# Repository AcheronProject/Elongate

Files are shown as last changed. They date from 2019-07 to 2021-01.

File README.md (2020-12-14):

# Acheron 50-SM-S-F072-MX-TH-WI (Codename "Elongate")

Acheron Logo

See [this page](https://gondolindrim.github.io/AcheronDocs/elongate/intro.html) for the ElongatePCB documentation.

## Supported layouts

Click [this link](http://www.keyboard-layout-editor.com/#/gists/a7ea70bf0b0dbade28f4dd3f8dd61796) for the KLE file for Elongate.

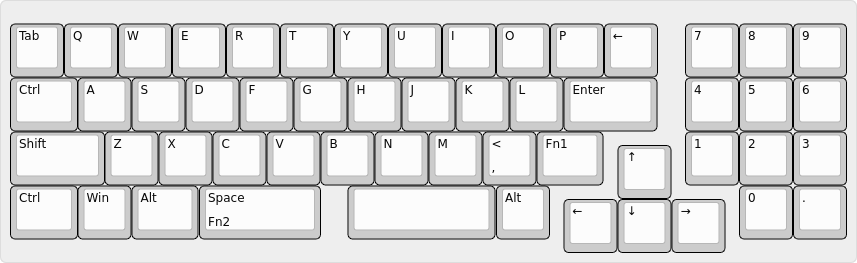
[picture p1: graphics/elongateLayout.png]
Elongate layouts


## Renders

Click at the images to zoom in.

Renders generated by the [tracespace.io](https://tracespace.io/view/) site.

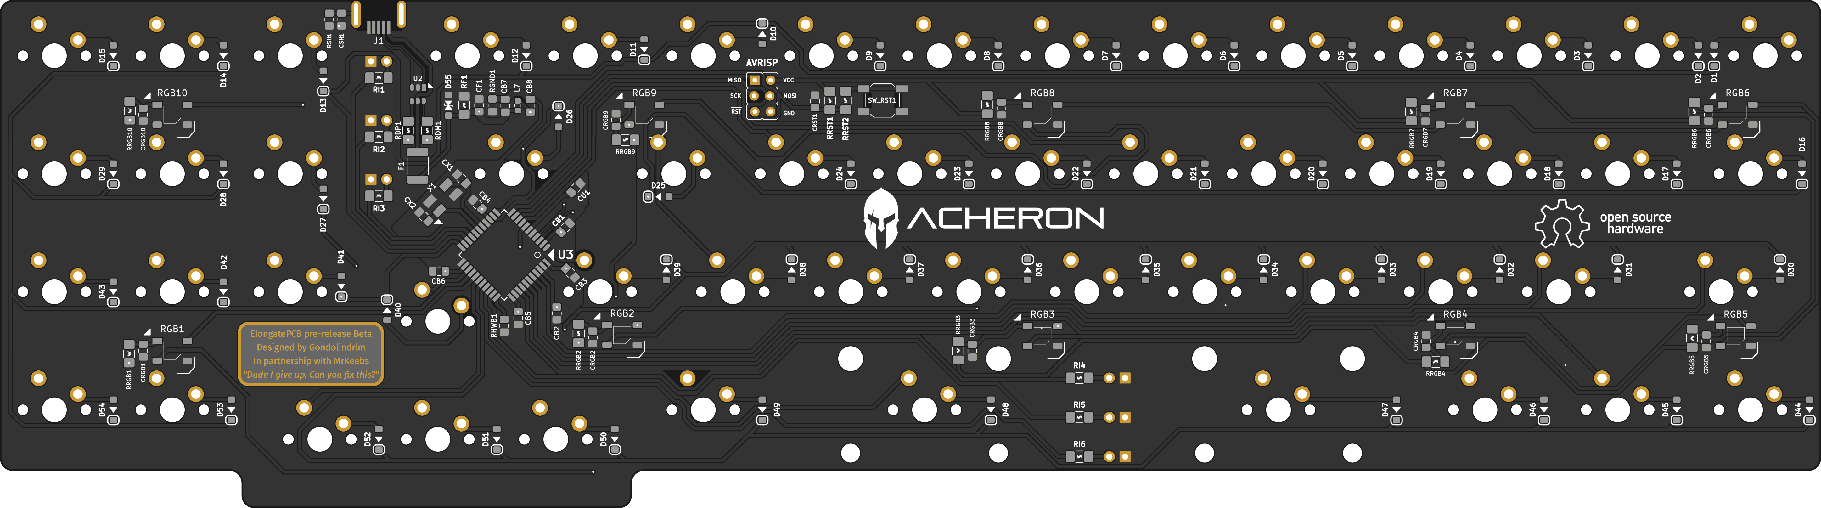
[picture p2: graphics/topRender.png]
Elongate PCB Top Render


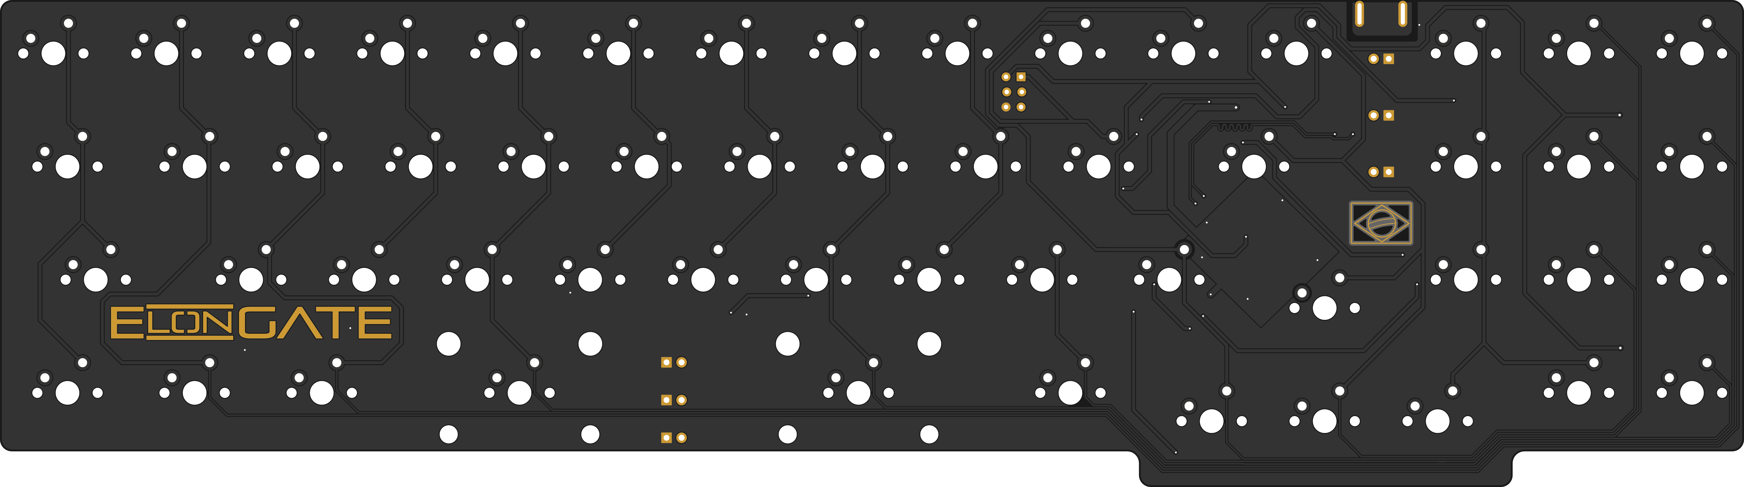
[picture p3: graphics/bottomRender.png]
Elongate PCB Bottom Render


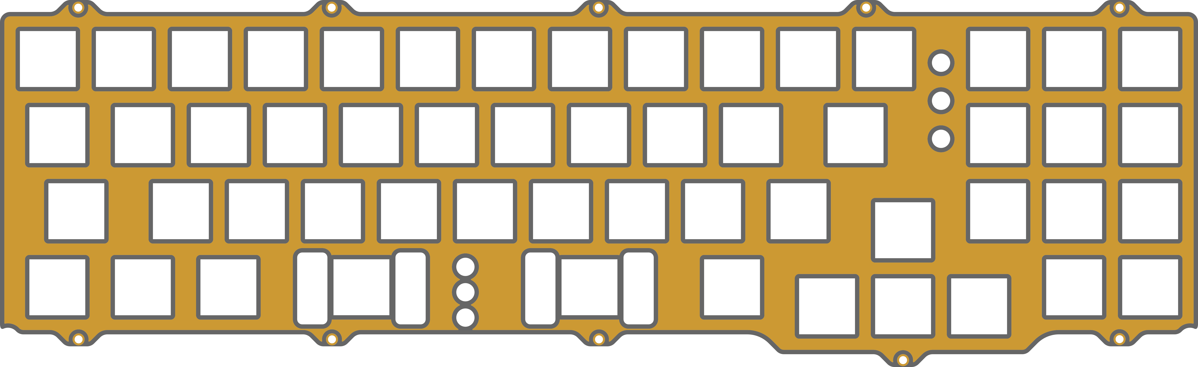
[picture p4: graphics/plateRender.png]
Elongate PCB Plate Render


## Copyright notice

This project is released under the Acheron Open-Hardware License V1.3. For the license, please refer to the LICENCE.md file.

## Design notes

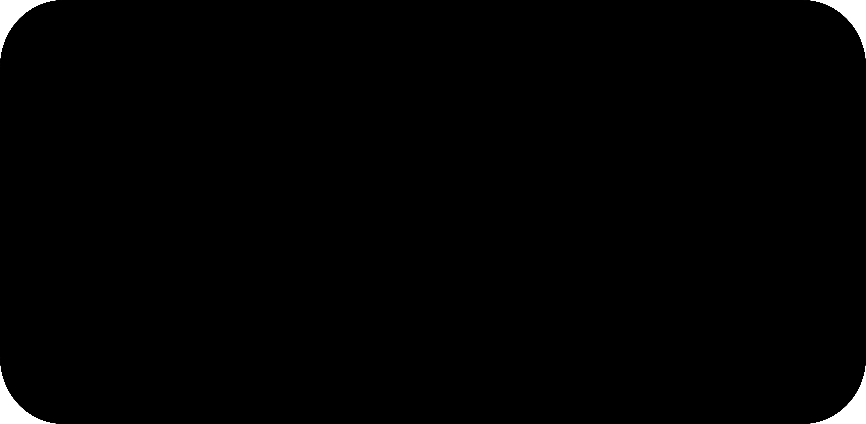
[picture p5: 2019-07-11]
graphics/label_logo/elongateLabelMask.png

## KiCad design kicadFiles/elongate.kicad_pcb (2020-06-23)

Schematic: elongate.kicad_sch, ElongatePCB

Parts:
C1, C2: 100n; C_0805_2012Metric_Pad1.15x1.40mm_HandSolder
C3, C12, C13, C14, C15, C16, C17, C18, C19, C20, C21, C22, C23, C24, C25, C26, C27, C30: 1u; C_0805_2012Metric_Pad1.15x1.40mm_HandSolder
C4, C5, C6, C10: 100n; C_0402_1005Metric
C7, C11: 4.7u; C_0402_1005Metric
C8: 1u; C_0402_1005Metric
C9: 10n; C_0402_1005Metric
C28: 100u; C_0805_2012Metric_Pad1.15x1.40mm_HandSolder
C29: 10u; C_0805_2012Metric_Pad1.15x1.40mm_HandSolder
D1, D2, D3, D4, D5, D6, D7, D8, D9, D10, D11, D12, D13, D14, D15, D16, D17, D18, D19, D20, D21, D22, D23, D24, D25, D26, D27, D28, D29, D30, D31, D32, D33, D34, D35, D36, D37, D38, D39, D40, D41, D42, D43, D44, D45, D46, D47, D48, D49, D50, D51, D52, D53, D54, D72: 1N4148; D_SOD-123
D55: SMF9.0CA; D_SOD-123_Bidirectional; Manufacturer Part Number SMF9.0CA; LCSC Part Number C435473
D56, D57, D58, D59, D60, D61, D62, D63, D64, D65, D66, D67, D68, D69, D70, D71: WS2812C; LED_WS2812B_5.0x5.0mm_P3.2mm; Manufacturer Part Number WS2812C; LCSC Part Number C114587
D73: RB060M-60TR; D_SOD-123; Manufacturer Part Number RB060M-60TR; LCSC Part Number C114257
F1: RF1338-000; Fuse_1812_4532Metric_Pad1.30x3.40mm_HandSolder; Manufacturer Part Number RF1338-000; LCSC Part Number C207188
J1: TYPE-C-31-M12_13; TYPE-C-31-M-12; Manufacturer Part Number TYPE-C-31-M-12; LCSC Part Number C165948
J2: Conn_ARM_JTAG_SWD_10
J3: Conn_01x6; PinHeader_2x3_P2.54mm_Vertical
L1: AcheronLogo; acheronLong
L2: ElongateLogoPlated; elongateLogo
L3: ElongateLabel; elongateLabel
L4: OSHLogo; osh-logo
L5: BRFlag; brazilFlag
LED1, LED2, LED3, LED4, LED5, LED6, LED7, LED8, LED9, LED10, LED11, LED12, LED13, LED14, LED15, LED16, LED17, LED18, LED19, LED20, LED21, LED22, LED23, LED24, LED25, LED26, LED27, LED28, LED29, LED30, LED31, LED32, LED33, LED34, LED35, LED36, LED37, LED38, LED39, LED40, LED41, LED42, LED43, LED44, LED45, LED46, LED47, LED48, LED49, LED50, LED51, LED52, LED53, LED54, LED55, LED56, LED57, LED58, LED59, LED60: LED; LED_THT_2.54mm
Q1, Q3: AO3401A; SOT-23; Manufacturer Part Number AO3401A; LCSC Part Number C15127
Q2, Q4: DTC123JKAT146; SOT-23; Manufacturer Part Number DTC123JKAT146; LCSC Part Number C111724
R1, R2: 5.1k; R_0402_1005Metric
R3, R4: 1M; R_SMD_1206
R5, R6, R7, R8, R9, R10, R14, R15, R16, R17, R18, R19, R20, R21, R22, R23, R24, R25, R26, R27, R28, R29, R30, R31, R32, R33, R34, R35, R36, R37, R38, R39, R40, R41, R42, R43, R44, R45, R46, R47, R48, R49, R50, R51, R52, R53, R54, R55, R56, R57, R58, R59, R60, R61, R62, R63, R64, R65, R66, R67: 390R; R_SMD_1206
R11, R88, R90: 100k; R_SMD_1206
R12, R84, R86: 10k; R_SMD_1206
R13, R89: 100R; R_SMD_1206
R68, R69, R70, R71, R72, R73, R74, R75, R76, R77, R78, R79, R80, R81, R82, R83: 3R; R_SMD_1206
R85: 5.1k; R_SMD_1206
R87: 33k; R_SMD_1206
SW1, SW2, SW3, SW4, SW5, SW6, SW7, SW8, SW9, SW10, SW11, SW12, SW13, SW14, SW15, SW17, SW18, SW19, SW20, SW21, SW22, SW23, SW24, SW25, SW27, SW28, SW29, SW31, SW32, SW33, SW34, SW35, SW36, SW37, SW38, SW41, SW45, SW46, SW47, SW48, SW49, SW50, SW51, SW52, SW53, SW54: MXSwitch; MX100
SW16, SW39, SW40, SW42: MXSwitch; MX125
SW26, SW30: MXSwitch; MX175
SW43: MXSwitch; MX225R
SW44: MXSwitch; MX275R
SW55: K2-1187SQ-A4SW-06; smdPushBtn; Manufacturer Part Number K2-1187SQ-A4SW-06; LCSC Part Number C92584
U1: TPD4E05U06DQAR; USON-10_2.5x1.0mm_P0.5mm; Manufacturer Part Number TPD4E05U06DQAR; LCSC Part Number C138714
U2: STM32F072CBT6; LQFP-48_7x7mm_P0.5mm; Manufacturer Part Number STM32F072CBT6; LCSC Part Number C81720
U3: MCP1700-3302E; SOT-23; Manufacturer Part Number MCP1700-3302E/TT; LCSC Part Number C39051

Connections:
3V3: C4.2, C5.1, C6.1, C7.1, C8.2, C9.2, C10.1, C11.1, C30.2, D73.2 (A), J2.1 (VTref), J3.5, R90.1, SW55.1, U2.1 (VBAT), U2.9 (VDDA), U2.24 (VDD), U2.36 (VDDIO2), U2.48 (VDD), U3.2 (VO)
5V: C3.1, D55.2 (A2), D73.1 (K), F1.2, Q1.2 (S), R11.2, R12.1, R68.1, R69.1, R70.1, R71.1, R72.1, R73.1, R74.1, R75.1, R76.1, R77.1, R78.1, R79.1, R80.1, R81.1, R82.1, R83.1, R84.1, R85.1, U3.3 (VI)
/SHIELD: C1.1, C2.1, J1.S (SHIELD), R3.2, R4.2
BOOT0: C28.2, R87.1, R88.1, U2.44 (BOOT0)
Col1: SW1.1 (Col), SW16.1 (Col), SW30.1 (Col), SW40.1 (Col), U2.31 (TIM1_CH3/PA10)
Col2: SW2.1 (Col), SW17.1 (Col), SW41.1 (Col), U2.30 (TIM1_CH2/PA9)
Col3: SW3.1 (Col), SW18.1 (Col), SW31.1 (Col), SW42.1 (Col), U2.29 (TIM1_CH1/PA8)
Col4: SW4.1 (Col), SW19.1 (Col), SW32.1 (Col), U2.27 (PB14/SPI2_MISO/I2S2_MCK/I2C2_SDA/TIM15_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)
Col5: SW5.1 (Col), SW20.1 (Col), SW33.1 (Col), SW43.1 (Col), U2.25 (PB12)
Col6: SW6.1 (Col), SW21.1 (Col), SW34.1 (Col), U2.22 (PB11/TIM2_CH4/I2C2_SDA)
Col7: SW7.1 (Col), SW22.1 (Col), SW35.1 (Col), U2.21 (PB10/SPI2_SCK/I2C2_SCL/TIM2_CH3)
Col8: SW8.1 (Col), SW23.1 (Col), SW36.1 (Col), SW44.1 (Col), U2.20 (PB2)
Col9: SW9.1 (Col), SW24.1 (Col), SW37.1 (Col), U2.19 (PB1/TIM3_CH4/TIM14_CH1/ADC_IN9)
Col10: SW10.1 (Col), SW25.1 (Col), SW38.1 (Col), SW45.1 (Col), U2.17 (PA7/TIM3_CH2/TIM14_CH1/ADC_IN7)
Col11: SW11.1 (Col), SW39.1 (Col), SW46.1 (Col), U2.15 (PA5/ADC_IN5/DAC_OUT2)
Col12: SW12.1 (Col), SW26.1 (Col), SW47.1 (Col), SW51.1 (Col), U2.46 (SPI2_NSS/I2S2_WS/I2C1_SDA/TIM17_CH1/PB9)
Col13: SW13.1 (Col), SW27.1 (Col), SW48.1 (Col), SW52.1 (Col), U2.45 (I2C1_SCL/TIM16_CH1/PB8)
Col14: SW14.1 (Col), SW28.1 (Col), SW49.1 (Col), SW53.1 (Col), U2.43 (2C1_SDA/PB7)
Col15: SW15.1 (Col), SW29.1 (Col), SW50.1 (Col), SW54.1 (Col), U2.42 (I2C1_SCL/PB6)
D+: J1.A6 (D+), J1.B6 (D+), U1.2 (IO2), U1.5 (D2-), U1.6 (NC), U1.9 (NC), U2.33 (USB_DP/PA12)
D-: J1.A7 (D-), J1.B7 (D-), U1.1 (IO1), U1.4 (D2+), U1.7 (NC), U1.10 (NC), U2.32 (USB_DM/TIM1_CH4/PA11)
EXTRA_1: J3.1, U2.2 (PC13)
EXTRA_2: J3.2, U2.3 (PC14/OSC32_IN)
EXTRA_3: J3.3, U2.4 (PC15/OSC32_OUT)
EXTRA_4: J3.4, U2.5 (PF0/OSC_IN)
GND: C1.2, C2.2, C3.2, C4.1, C5.2, C6.2, C7.2, C8.1, C9.1, C10.2, C11.2, C12.2, C13.2, C14.2, C15.2, C16.2, C17.2, C18.2, C19.2, C20.2, C21.2, C22.2, C23.2, C24.2, C25.2, C26.2, C27.2, C28.1, C29.1, C30.1, D55.1 (A1), D56.3 (VSS), D57.3 (VSS), D58.3 (VSS), D59.3 (VSS), D60.3 (VSS), D61.3 (VSS), D62.3 (VSS), D63.3 (VSS), D64.3 (VSS), D65.3 (VSS), D66.3 (VSS), D67.3 (VSS), D68.3 (VSS), D69.3 (VSS), D70.3 (VSS), D71.3 (VSS), J1.A1 (GND), J1.B1 (GND), J2.3 (GND), J2.5 (GND), J2.9 (GNDDetect), J3.6, LED1.K, LED2.K, LED3.K, LED4.K, LED5.K, LED6.K, LED7.K, LED8.K, LED9.K, LED10.K, LED11.K, LED12.K, LED13.K, LED14.K, LED15.K, LED16.K, LED17.K, LED18.K, LED19.K, LED20.K, LED21.K, LED22.K, LED23.K, LED24.K, LED25.K, LED26.K, LED27.K, LED28.K, LED29.K, LED30.K, LED31.K, LED32.K, LED33.K, LED34.K, LED35.K, LED36.K, LED37.K, LED38.K, LED39.K, LED40.K, LED41.K, LED42.K, LED43.K, LED44.K, LED45.K, LED46.K, LED47.K, LED48.K, LED49.K, LED50.K, LED51.K, LED52.K, LED53.K, LED54.K, LED55.K, LED56.K, LED57.K, LED58.K, LED59.K, LED60.K, Q2.2 (E), Q4.2 (E), R1.1, R2.1, R3.1, R4.1, R11.1, R86.2, R88.2, R90.2, U1.3 (GND), U1.8 (GND), U2.8 (VSSA), U2.23 (VSS), U2.35 (VSS), U2.47 (VSS), U3.1 (GND)
INDICATOR1: R5.1, U2.12 (PA2/ADC_IN2)
INDICATOR2: R6.1, U2.11 (PA1/ADC_IN1)
INDICATOR3: R7.1, U2.10 (PA0/ADC_IN0)
INDICATOR4: R8.1, U2.14 (PA4/TIM14_CH1/ADC_IN4)
INDICATOR5: R9.1, U2.13 (PA3/TIM15_CH2/ADC_IN3)
INDICATOR6: R10.1, U2.6 (PF1/OSC_OUT)
LED_PWM: Q2.1 (B), U2.16 (PA6/ADC_IN6/TIM3_CH1/TIM16_CH1)
unnamed: C12.1, D56.1 (VDD), R68.2
unnamed: C13.1, D57.1 (VDD), R69.2
unnamed: C14.1, D58.1 (VDD), R70.2
unnamed: C15.1, D59.1 (VDD), R71.2
unnamed: C16.1, D60.1 (VDD), R72.2
unnamed: C17.1, D61.1 (VDD), R73.2
unnamed: C18.1, D62.1 (VDD), R74.2
unnamed: C19.1, D63.1 (VDD), R75.2
unnamed: C20.1, D64.1 (VDD), R76.2
unnamed: C21.1, D65.1 (VDD), R77.2
unnamed: C22.1, D66.1 (VDD), R78.2
unnamed: C23.1, D67.1 (VDD), R79.2
unnamed: C24.1, D68.1 (VDD), R80.2
unnamed: C25.1, D69.1 (VDD), R81.2
unnamed: C26.1, D70.1 (VDD), R82.2
unnamed: C27.1, D71.1 (VDD), R83.2
unnamed: D1.2 (A), SW1.2 (Row)
unnamed: D2.2 (A), SW2.2 (Row)
unnamed: D3.2 (A), SW3.2 (Row)
unnamed: D4.2 (A), SW4.2 (Row)
unnamed: D5.2 (A), SW5.2 (Row)
unnamed: D6.2 (A), SW6.2 (Row)
unnamed: D7.2 (A), SW7.2 (Row)
unnamed: D8.2 (A), SW8.2 (Row)
unnamed: D9.2 (A), SW9.2 (Row)
unnamed: D10.2 (A), SW10.2 (Row)
unnamed: D11.2 (A), SW11.2 (Row)
unnamed: D12.2 (A), SW12.2 (Row)
unnamed: D13.2 (A), SW13.2 (Row)
unnamed: D14.2 (A), SW14.2 (Row)
unnamed: D15.2 (A), SW15.2 (Row)
unnamed: D16.2 (A), SW16.2 (Row)
unnamed: D17.2 (A), SW17.2 (Row)
unnamed: D18.2 (A), SW18.2 (Row)
unnamed: D19.2 (A), SW19.2 (Row)
unnamed: D20.2 (A), SW20.2 (Row)
unnamed: D21.2 (A), SW21.2 (Row)
unnamed: D22.2 (A), SW22.2 (Row)
unnamed: D23.2 (A), SW23.2 (Row)
unnamed: D24.2 (A), SW24.2 (Row)
unnamed: D25.2 (A), SW25.2 (Row)
unnamed: D26.2 (A), SW26.2 (Row)
unnamed: D27.2 (A), SW27.2 (Row)
unnamed: D28.2 (A), SW28.2 (Row)
unnamed: D29.2 (A), SW29.2 (Row)
unnamed: D30.2 (A), SW30.2 (Row)
unnamed: D31.2 (A), SW31.2 (Row)
unnamed: D32.2 (A), SW32.2 (Row)
unnamed: D33.2 (A), SW33.2 (Row)
unnamed: D34.2 (A), SW34.2 (Row)
unnamed: D35.2 (A), SW35.2 (Row)
unnamed: D36.2 (A), SW36.2 (Row)
unnamed: D37.2 (A), SW37.2 (Row)
unnamed: D38.2 (A), SW38.2 (Row)
unnamed: D39.2 (A), SW39.2 (Row)
unnamed: D40.2 (A), SW40.2 (Row)
unnamed: D41.2 (A), SW41.2 (Row)
unnamed: D42.2 (A), SW42.2 (Row)
unnamed: D43.2 (A), SW43.2 (Row)
unnamed: D44.2 (A), SW44.2 (Row)
unnamed: D45.2 (A), SW45.2 (Row)
unnamed: D46.2 (A), SW46.2 (Row)
unnamed: D47.2 (A), SW47.2 (Row)
unnamed: D48.2 (A), SW48.2 (Row)
unnamed: D49.2 (A), SW49.2 (Row)
unnamed: D50.2 (A), SW50.2 (Row)
unnamed: D51.2 (A), SW51.2 (Row)
unnamed: D52.2 (A), SW52.2 (Row)
unnamed: D53.2 (A), SW53.2 (Row)
unnamed: D54.2 (A), SW54.2 (Row)
unnamed: D56.2 (DOUT), D57.4 (DIN)
unnamed: D57.2 (DOUT), D58.4 (DIN)
unnamed: D58.2 (DOUT), D59.4 (DIN)
unnamed: D59.2 (DOUT), D60.4 (DIN)
unnamed: D60.2 (DOUT), D61.4 (DIN)
unnamed: D61.2 (DOUT), D62.4 (DIN)
unnamed: D62.2 (DOUT), D63.4 (DIN)
unnamed: D63.2 (DOUT), D64.4 (DIN)
unnamed: D64.2 (DOUT), D65.4 (DIN)
unnamed: D65.2 (DOUT), D66.4 (DIN)
unnamed: D66.2 (DOUT), D67.4 (DIN)
unnamed: D67.2 (DOUT), D68.4 (DIN)
unnamed: D68.2 (DOUT), D69.4 (DIN)
unnamed: D69.2 (DOUT), D70.4 (DIN)
unnamed: D70.2 (DOUT), D71.4 (DIN)
unnamed: D72.1 (K), R87.2
unnamed: D72.2 (A), Q4.1 (B), SW55.2
unnamed: J1.A5 (CC1), R1.2
unnamed: J1.B5 (CC2), R2.2
unnamed: LED1.A, R5.2
unnamed: LED2.A, R6.2
unnamed: LED3.A, R7.2
unnamed: LED4.A, R8.2
unnamed: LED5.A, R9.2
unnamed: LED6.A, R10.2
unnamed: LED7.A, R14.2
unnamed: LED8.A, R15.2
unnamed: LED9.A, R16.2
unnamed: LED10.A, R17.2
unnamed: LED11.A, R18.2
unnamed: LED12.A, R19.2
unnamed: LED13.A, R20.2
unnamed: LED14.A, R21.2
unnamed: LED15.A, R22.2
unnamed: LED16.A, R23.2
unnamed: LED17.A, R24.2
unnamed: LED18.A, R25.2
unnamed: LED19.A, R26.2
unnamed: LED20.A, R27.2
unnamed: LED21.A, R28.2
unnamed: LED22.A, R29.2
unnamed: LED23.A, R30.2
unnamed: LED24.A, R31.2
unnamed: LED25.A, R32.2
unnamed: LED26.A, R33.2
unnamed: LED27.A, R34.2
unnamed: LED28.A, R35.2
unnamed: LED29.A, R36.2
unnamed: LED30.A, R37.2
unnamed: LED31.A, R38.2
unnamed: LED32.A, R39.2
unnamed: LED33.A, R40.2
unnamed: LED34.A, R41.2
unnamed: LED35.A, R42.2
unnamed: LED36.A, R43.2
unnamed: LED37.A, R44.2
unnamed: LED38.A, R45.2
unnamed: LED39.A, R46.2
unnamed: LED40.A, R47.2
unnamed: LED41.A, R48.2
unnamed: LED42.A, R49.2
unnamed: LED43.A, R50.2
unnamed: LED44.A, R51.2
unnamed: LED45.A, R52.2
unnamed: LED46.A, R53.2
unnamed: LED47.A, R54.2
unnamed: LED48.A, R55.2
unnamed: LED49.A, R56.2
unnamed: LED50.A, R57.2
unnamed: LED51.A, R58.2
unnamed: LED52.A, R59.2
unnamed: LED53.A, R60.2
unnamed: LED54.A, R61.2
unnamed: LED55.A, R62.2
unnamed: LED56.A, R63.2
unnamed: LED57.A, R64.2
unnamed: LED58.A, R65.2
unnamed: LED59.A, R66.2
unnamed: LED60.A, R67.2
unnamed: Q1.1 (G), R13.1
unnamed: Q1.3 (D), R14.1, R15.1, R16.1, R17.1, R18.1, R19.1, R20.1, R21.1, R22.1, R23.1, R24.1, R25.1, R26.1, R27.1, R28.1, R29.1, R30.1, R31.1, R32.1, R33.1, R34.1, R35.1, R36.1, R37.1, R38.1, R39.1, R40.1, R41.1, R42.1, R43.1, R44.1, R45.1, R46.1, R47.1, R48.1, R49.1, R50.1, R51.1, R52.1, R53.1, R54.1, R55.1, R56.1, R57.1, R58.1, R59.1, R60.1, R61.1, R62.1, R63.1, R64.1, R65.1, R66.1, R67.1
unnamed: Q2.3 (C), R12.2, R13.2
unnamed: Q3.1 (G), R85.2, R86.1
unnamed: Q4.3 (C), R89.2
RGB_3V3: Q3.3 (D), U2.28 (SPI2_MOSI/I2S2_SD/PB15)
RGB_5V: D56.4 (DIN), Q3.2 (S), R84.2
Row1: D1.1 (K), D2.1 (K), D3.1 (K), D4.1 (K), D5.1 (K), D6.1 (K), D7.1 (K), D8.1 (K), D9.1 (K), D10.1 (K), D11.1 (K), D12.1 (K), D13.1 (K), D14.1 (K), D15.1 (K), U2.39 (SPI1_SCK/I2S1_CK/TIM2_CH2/PB3)
Row2: D16.1 (K), D17.1 (K), D18.1 (K), D19.1 (K), D20.1 (K), D21.1 (K), D22.1 (K), D23.1 (K), D24.1 (K), D25.1 (K), D26.1 (K), D27.1 (K), D28.1 (K), D29.1 (K), U2.38 (PA2)
Row3: D30.1 (K), D31.1 (K), D32.1 (K), D33.1 (K), D34.1 (K), D35.1 (K), D36.1 (K), D37.1 (K), D38.1 (K), D39.1 (K), U2.18 (PB0/TIM3_CH3/ADC_IN8)
Row4: D40.1 (K), D41.1 (K), D42.1 (K), D43.1 (K), D44.1 (K), D45.1 (K), D46.1 (K), D47.1 (K), D48.1 (K), D49.1 (K), D50.1 (K), U2.40 (SPI1_MISO/I2S1_MCK/TIM3_CH1/PB4)
Row5: D51.1 (K), D52.1 (K), D53.1 (K), D54.1 (K), U2.41 (SPI1_MOSI/I2S1_SD/TIM3_CH2/PB5)
SWCLK: J2.4 (SWDCLK/TCK), U2.37 (SWCLK/PA14)
SWDIO: J2.2 (SWDIO/TMS), U2.34 (SWDIO/PA13)
VBUS: F1.1, J1.A4 (VBUS), J1.B4 (VBUS)
nRST: C29.2, J2.10 (~RESET~), R89.1, U2.7 (NRST)

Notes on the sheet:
MCU Shenanigans
Indicator LEDs
USB Connector
Logos
RGB
MCU Reset
Switch Matrix
CTRL
SHFT
TAB
WIN
ALT
LDO
Fn2
SPC
JTAG SWD
LEFT
ENTER
BKSP
DOWN
RIGHT
DOT
ESD protection
LEDs

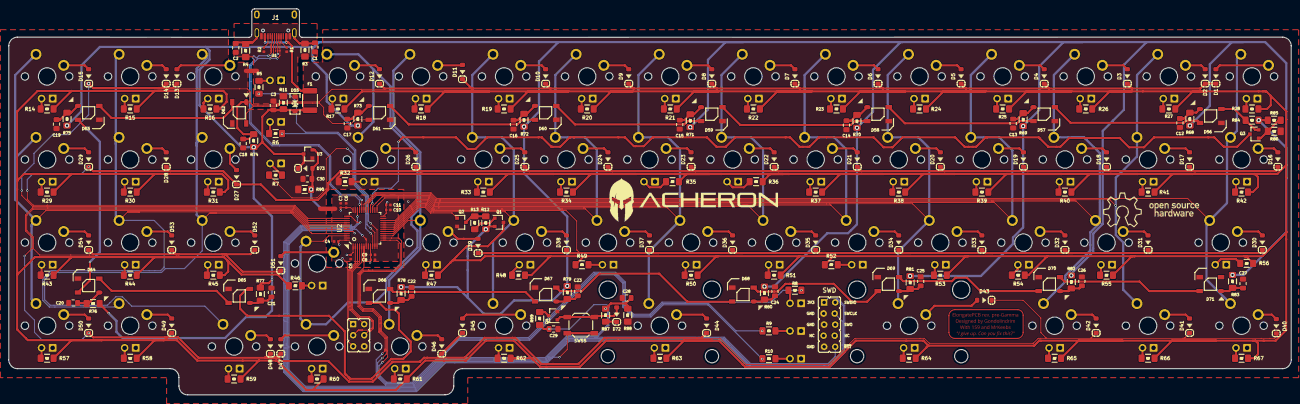
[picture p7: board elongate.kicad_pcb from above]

Board: 2 copper layers, 294.0 x 88.5 mm, 324 parts (1 on the bottom side), 198 nets.

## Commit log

2019-07-10 [Update] Swapped all footprint to Acheron Library, finished schematic
    [elongate-B.Cu.gbr, elongate-B.Mask.gbr, elongate-B.Paste.gbr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]
2019-07-10 [Update] Finished placing components. Almost done routing. Logos still pending.
    [elongate.kicad_pcb, elongate.sch]
2019-07-11 [Update] Finished routing
    [elongate.kicad_pcb, elongate.sch]
2019-07-11 [Update] Added logos and label
    [elongate.kicad_pcb, elongate.sch]
2019-07-12 [Update] Updated gerbers, added plate gerber files
    [elongate-B.Cu.gbr, elongate-B.Mask.gbr, elongate-B.Paste.gbr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]
2019-08-26 feat: added script to parse BOM CSV
2019-08-27 Started mirroring PCB
    [elongate.kicad_pcb]
2019-09-01 Breakout pins, refresh gerbers
    [elongate.kicad_pcb, elongate.sch, elongatePlate.kicad_pcb]
2019-09-01 Added renders, LICENSE and README
    [plate.dxf]
2019-09-01 Added schematic PDF
2019-09-01 Added BOM csv file
    [elongate_BOM.csv]
2019-09-11 Fix pins 34/35, optimized VCC routing
    - I dun goofed with the routing of pins 34 and 35, which are respectively VCC and GND, and they were routed the opposite way, which caused a short-circuit between VCC and GND, hindering be board bricked.
    - There was a little optimization in the routing of the 5V net, specifically the trace going from the fuse. That trace was supposed to go trhough DF1, RF1 and CF1 and then to the MCU, when in reality the trace was coming directly from F1, precarizing the functionality of DF1, RF1 and CF1.
    - A new schematic file was added to ./manuFiles/ folder
    - Gerbers were refreshed
    [elongate.kicad_pcb, elongate.sch]
2019-09-11 Refreshed schematic PDF file
2019-09-12 Added ISP header to schematic
    [elongate.sch]
2019-09-13 Expose ISP pins, rewire two cols
    - The ISP pins (PB1, PB2, PB3, RST, GND, VCC) were exposed ("broken out") so that ISP is more easily done;
    - Col 1 and col 2 were reassigned in the microcontroller for a better feeling
    [elongate.kicad_pcb, elongate.sch]
2019-09-13 Add RGB WS2812 LEDs to schematic
    [elongate.kicad_pcb, elongate.sch]
2019-09-13 Refresh gerbers and schematic PDF. Tag V1.2
    [elongate.kicad_pcb, elongate.sch]
2019-09-13 Refreshed schematic PDF
2019-10-28 Fix plate issues, final DRC run
    [elongatePlate.kicad_pcb, elongate_BOM.csv]
2019-10-28 Update label to 'Revision Alpha'
    [elongate.kicad_pcb]
2019-11-30 Add TVS, RGB, pi filter, new diodes and switches to the schematic
    [elongate.kicad_pcb, elongate.sch]
2019-12-01 Finish routing, run DRC
    [elongate.kicad_pcb, elongate.sch]
2019-12-01 Update PCB file
    [elongate.kicad_pcb]
2019-12-01 Update F.Fab layer
    [elongate.kicad_pcb]
2019-12-01 Update renders
    [elongate.kicad_pcb, elongate.sch, elongatePlate.kicad_pcb]
2019-12-01 Update README with plate render
2020-01-31 Pre-revision Beta release
    [elongate.kicad_pcb, elongatePlate.kicad_pcb]
2020-05-26 PCB global deletion and USBC connector port
    [elongate.kicad_pcb, elongate.kicad_sch, elongate.sch]
2020-06-21 Change RCC resistors to R0402
    [elongate.kicad_pcb, elongate.kicad_sch]
2020-06-21 Added LEDs
    [elongate.kicad_pcb, elongate.kicad_sch]
2020-06-21 Finish LED placin, add MCU
    [elongate.kicad_pcb, elongate.kicad_sch]
2020-06-21 Almost finish routing, DRC pending
    [elongate.kicad_pcb, elongate.kicad_sch]
2020-06-23 Finish routing
    [elongate.kicad_pcb, elongate.kicad_sch]
2020-06-23 DRC ran, added indicators
    [elongate.kicad_pcb, elongate.kicad_sch]
2020-06-23 Solve symbol fields issues, prepare for pre-release Gamma
    [elongate.kicad_pcb, elongate.kicad_sch]
2020-06-23 Export pre-gamma files
    [elongate.kicad_pcb]
2020-12-14 Shortened USB lip to 10.2mm
2020-12-14 Solved level translator circuit issues
    [elongate.kicad_sch]
2020-12-14 Changed indicators as open-collector current sinks
    [elongate.kicad_sch]
2021-01-16 Remove reduntant files, remove AcheronLib submodule to update
    [elongate.kicad_sch, elongatePlate.kicad_pcb]
2021-01-16 Added new Wurth USBC connector
    [elongate.kicad_sch]
2021-01-28 Change all silkscreen markings to 25/25/5 mil sizes
    [elongate.kicad_sch]
2021-01-28 Changed SWD for 6-pin equivalent
    [elongate.kicad_sch]
2021-01-29 Change LDO regulating caps to tantallums
    [elongate.kicad_sch]
2021-01-30 Add metadata to connector, move RCC resistors
    [elongate.kicad_sch]
2021-01-31 DRC ran, new label
    [elongate.kicad_sch]
2021-07-01 Updated fills, DRC ran, erros corrected
    [elongate.kicad_sch]
2021-07-01 Updated component metatada
    [elongate.kicad_sch]
